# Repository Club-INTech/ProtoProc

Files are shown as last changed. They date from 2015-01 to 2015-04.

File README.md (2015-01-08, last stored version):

# ProtoProc #

## Equipe: ##
- Dédé Belnet
- Martial Costantini
- Pierre-François Gimenez

# Projet: #
Concevoir et construire une console de jeu avec des portes logiques.

## Etapes ##
- concevoir un processeur RISC
- le réaliser électroniquement
- écrire un assembleur
- écrire un compilateur (?)
- écrire un jeu
- intégrer des éléments extérieurs (écran, manette)
- jouer

## Constituant d'un processeur ##
- ALU (unité arithmétique et logique)
- Register file
- Séquenceur
- Horloge
- Contrôleur mémoire
- Contrôleur d'interruption
- MMU

A se répartir.

## Eléments à choisir ##
- Combien de bits? (bits effectivement utilisés + bits de redondance)
- Quels adressages disponibles?
- Jeu d'instruction? (voir plus bas)
- Mode idle?
- Timer? Compteur?

### Proposition ###
- 3 bits (données)
- 8 registres accessibles: ACC1, ACC2, SP (accessible?), flags (zero, sign, carry) (accessible?), index high, index low, E/S 1 (ou seulement entrée), E/S 2 (ou seulement sortie). Registre nul? (utile pour comparaison à zéro et initialisation)
- adressage sur 15 bits immédiats (cf largeur du bus de la mémoire ram de RS)
- adresse sur 15 bits immédiats + 6 bits provenant des deux registres d'index (une adresse du genre 1400 + INDEX)

## Matériel utilisé ##
- transistor
- portes logiques
- décodeur ?
- bascule ?
- (dé)multiplexeur ?
- eeprom ? (mémoire programme et microcode) (utiliser communication parallèle: http://fr.rs-online.com/web/p/memoires-eeprom/0394504/)
- ram ? (mémoire données et mémoire de la carte graphique. Y'a pas de SDRAM traversant chez RS mais y'a du SRAM: http://fr.rs-online.com/web/p/memoires-sram/0538148/)

L'avantage avec un processeur lent, c'est que les temps d'accès mémoire se font en un tic d'horloge...

## Jeu d'instructions ##
Si on veut un jeu rapide, il ne faut pas se contenter de quelques instructions mais ajouter des instructions assez haut niveau.
Il y a deux sortes d'instructions: les câblés (inaltérables) et les micro-codés (programmable).
Les câblés sont plus rapides que les micro-codés, mais consomment beaucoup de portes logiques.

### Instructions câblée monocycle ###
- mov
- Instructions logiques et arithmétiques sur deux registres
- Saut conditionnel (se base sur les flags)
- Saut inconditionnel
- load/store
- nop

### Instructions microcodées à voir selon le jeu. ###
- Pile ? (push, pop, call, ret)
- load/store avec index?
- Echange du contenu de deux registres ?
- Comparaison suivi d'un saut ?
- Instructions sur des booléens ?
- Instructions mémoire-registre ?
- Une instruction de nop'ification qui permettrait de supprimer des branches et de faciliter le travail du pipeline.

Exemple, au lieu de:

```
#!Assembleur

    cmp A, 0
    jz Label1 // (saute si A == 0)
    mov B, 3
    mov A, 6
    jmp Label2
Label1:
    mov B, 9
    mov C, 4
Label2:
```

On aurait:

```
#!Assembleur

    cmp A, 0
    nopz 3 // (si A == 0, ignore les trois prochaines instructions)
    mov B, 3
    mov A, 6
    nop 2  // (ignore les deux prochaines instructions)
    mov B, 9
    mov C, 4
```

On perd du temps (les instructions ignorées durent un cycle chacune) mais cela retire en embranchement. Pour les branchements pour lesquels la nopification est impossible (label en arrière ou trop de code à noper), je rappelle qu'il faut toujours ajouter des nops après le branchement afin de ne pas exécuter les instructions en aval.

```
#!Assembleur

    cmp A, 0
    jz Label1 // saute si A == 0
    nop
    nop
    nop
    (ABWABWA)
Label1:
    (ABWABWABWABWAAAA)
```

## Idées ##
- Un jeu d'instruction dynamique (qui change sans que le processeur ne s'éteigne)
- Il faudrait en plus du processeur et de sa mémoire, une carte son (pour jouer de la musique avec un floppy) et une carte graphique (qui transmet les informations de la mémoire à la matrice de led). Les fréquences de ces trois systèmes ne sont pas forcément les mêmes.
- La carte graphique pourrait gérer une matrice de diode pour les images et des afficheurs 7 segments pour les nombres. Voire utiliser un petit écran LCD.

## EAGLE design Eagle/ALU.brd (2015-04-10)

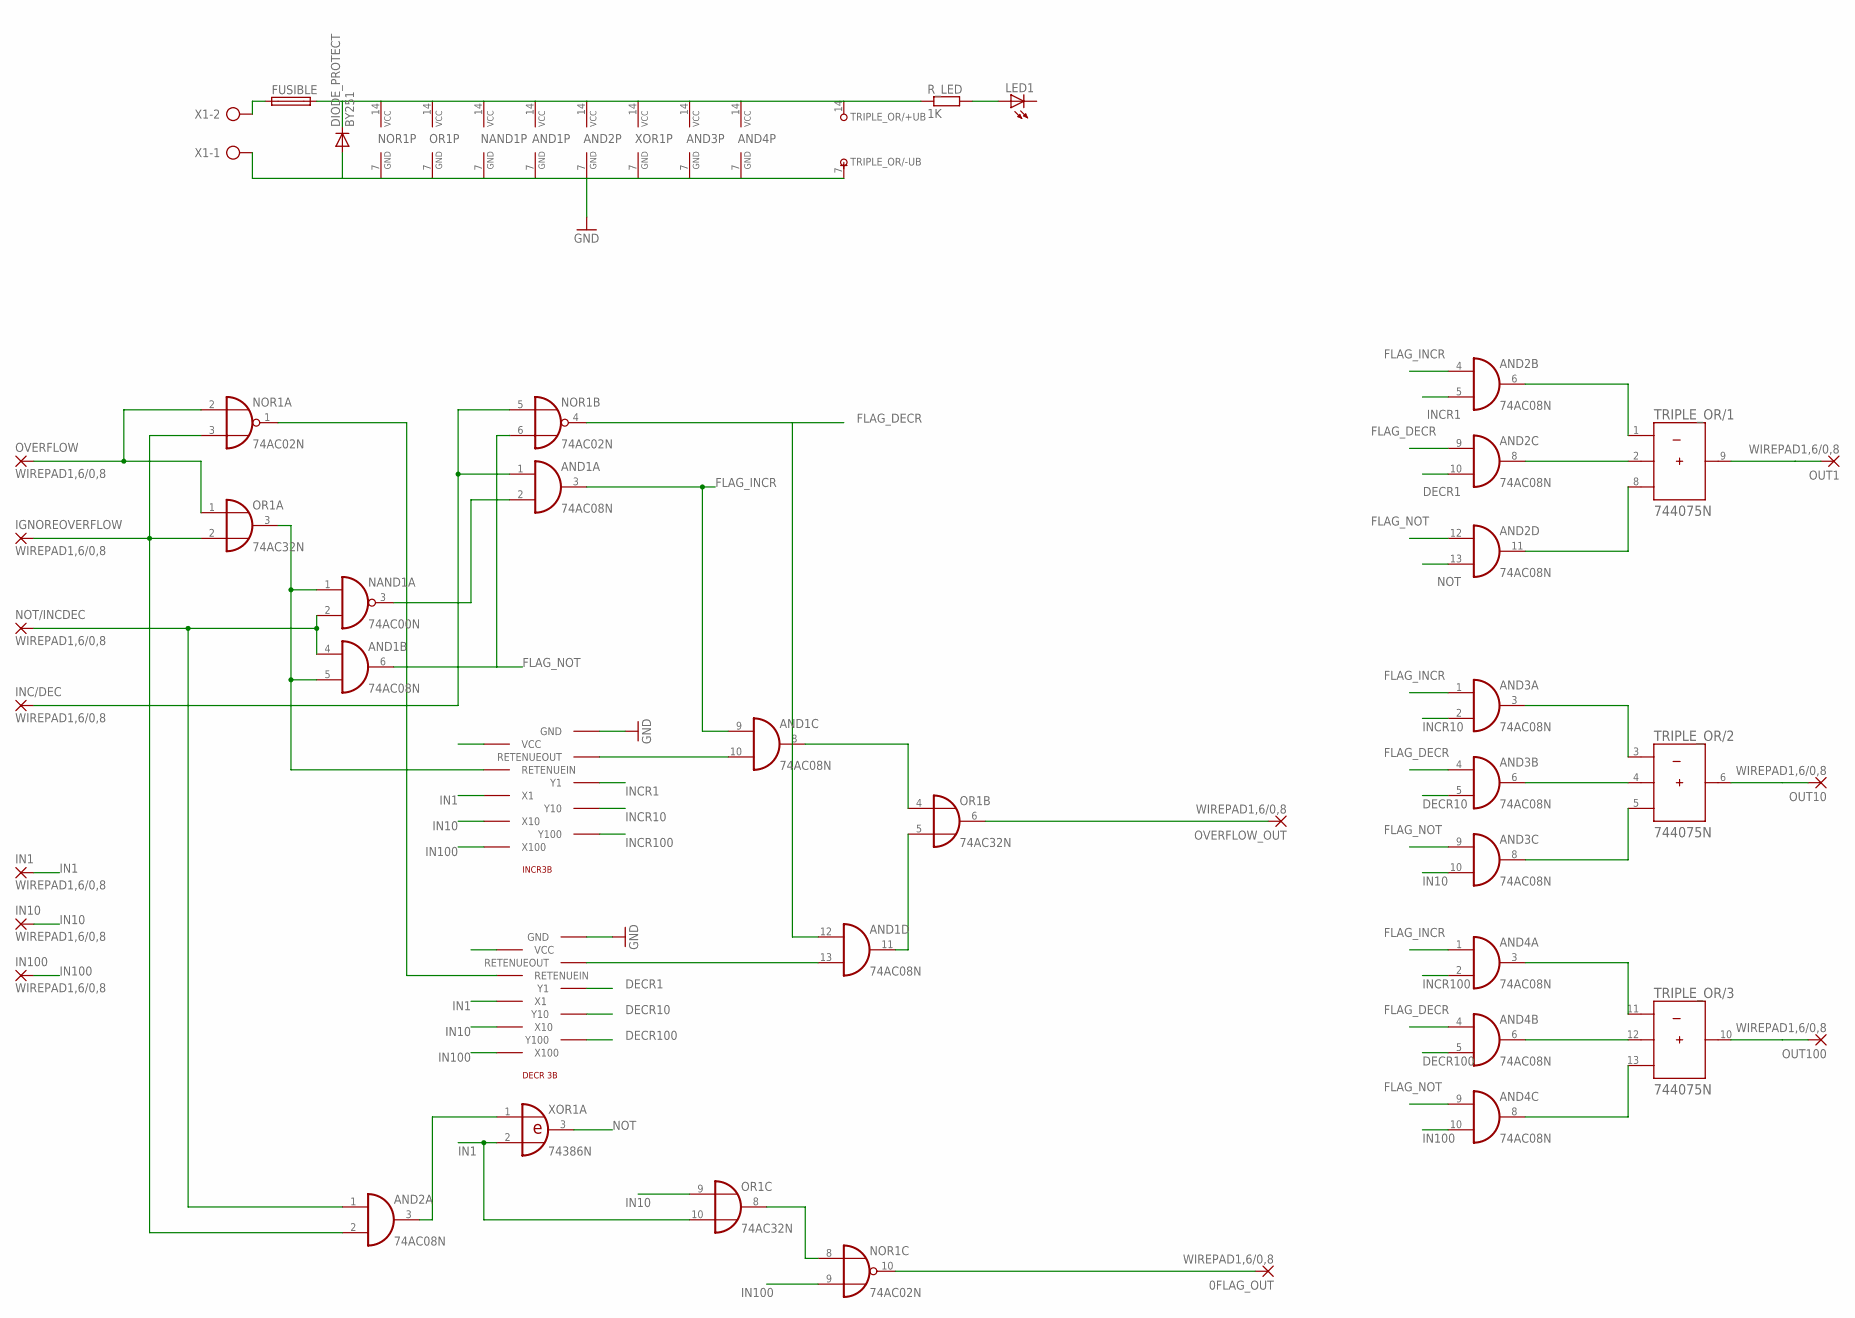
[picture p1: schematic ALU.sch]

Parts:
0FLAG_OUT: WIREPAD1,6/0,8; 1,6/0,8
AND1, AND2, AND3, AND4: 74AC08N; DIL14
DECR3B: DECR3B
DIODE_PROTECT: BY251; DO201-15
FUSIBLE: SH22,5A
IGNOREOVERFLOW: WIREPAD1,6/0,8; 1,6/0,8
IN1, IN10, IN100: WIREPAD1,6/0,8; 1,6/0,8
INC/DEC: WIREPAD1,6/0,8; 1,6/0,8
INCR3B: INCR3B
LED1: LEDSFH482; SFH482
NAND1: 74AC00N; DIL14
NOR1: 74AC02N; DIL14
NOT/INCDEC: WIREPAD1,6/0,8; 1,6/0,8
OR1: 74AC32N; DIL14
OUT1, OUT10, OUT100: WIREPAD1,6/0,8; 1,6/0,8
OVERFLOW: WIREPAD1,6/0,8; 1,6/0,8
OVERFLOW_OUT: WIREPAD1,6/0,8; 1,6/0,8
R_LED: 1K; 0207/10
TRIPLE_OR: 744075N; DIL14
X1: AK300/2
XOR1: 74386N; DIL14

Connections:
0FLAG_OUT: 0FLAG_OUT.1, NOR1.10 (O)
DECR1: AND2.10 (I1), DECR3B.Y1
DECR10: AND3.5 (I1), DECR3B.Y10
DECR100: AND4.5 (I1), DECR3B.Y100
FLAG_DECR: AND1.12 (I0), AND2.9 (I0), AND3.4 (I0), AND4.4 (I0), NOR1.4 (O)
FLAG_INCR: AND1.3 (O), AND1.9 (I0), AND2.4 (I0), AND3.1 (I0), AND4.1 (I0)
FLAG_NOT: AND1.6 (O), AND2.12 (I0), AND3.9 (I0), AND4.9 (I0), NOR1.6 (I1)
GND: AND1.7 (GND), AND2.7 (GND), AND3.7 (GND), AND4.7 (GND), DECR3B.GND, DIODE_PROTECT.A, INCR3B.GND, NAND1.7 (GND), NOR1.7 (GND), OR1.7 (GND), TRIPLE_OR.7 (-UB), X1.1, XOR1.7 (GND)
IN1: DECR3B.X1, IN1.1, INCR3B.X1, OR1.10 (I1), XOR1.2 (I1)
IN10: AND3.10 (I1), DECR3B.X10, IN10.1, INCR3B.X10, OR1.9 (I0)
IN100: AND4.10 (I1), DECR3B.X100, IN100.1, INCR3B.X100, NOR1.9 (I1)
INCR1: AND2.5 (I1), INCR3B.Y1
INCR10: AND3.2 (I1), INCR3B.Y10
INCR100: AND4.2 (I1), INCR3B.Y100
unnamed: NOR1.2 (I0), OR1.1 (I0), OVERFLOW.1
unnamed: AND2.6 (O), TRIPLE_OR.1 (A)
unnamed: AND1.2 (I1), NAND1.3 (O)
unnamed: AND1.1 (I0), INC/DEC.1, NOR1.5 (I0)
unnamed: AND1.4 (I0), AND2.1 (I0), NAND1.2 (I1), NOT/INCDEC.1
unnamed: AND1.5 (I1), INCR3B.RETENUEIN, NAND1.1 (I0), OR1.3 (O)
unnamed: AND2.8 (O), TRIPLE_OR.2 (B)
unnamed: DECR3B.RETENUEIN, NOR1.1 (O)
unnamed: AND1.8 (O), OR1.4 (I0)
unnamed: AND1.13 (I1), DECR3B.RETENUEOUT
unnamed: AND1.10 (I1), INCR3B.RETENUEOUT
unnamed: AND1.11 (O), OR1.5 (I1)
unnamed: OR1.6 (O), OVERFLOW_OUT.1
unnamed: AND2.2 (I1), IGNOREOVERFLOW.1, NOR1.3 (I1), OR1.2 (I1)
unnamed: AND2.3 (O), XOR1.1 (I0)
unnamed: NOR1.8 (I0), OR1.8 (O)
unnamed: AND2.11 (O), TRIPLE_OR.8 (C)
unnamed: FUSIBLE.1, X1.2
unnamed: LED1.A, R_LED.2
unnamed: AND3.3 (O), TRIPLE_OR.3 (A)
unnamed: AND3.6 (O), TRIPLE_OR.4 (B)
unnamed: AND3.8 (O), TRIPLE_OR.5 (C)
unnamed: AND4.3 (O), TRIPLE_OR.11 (A)
unnamed: AND4.6 (O), TRIPLE_OR.12 (B)
unnamed: AND4.8 (O), TRIPLE_OR.13 (C)
NOT: AND2.13 (I1), XOR1.3 (O)
OUT1: OUT1.1, TRIPLE_OR.9 (Y)
OUT10: OUT10.1, TRIPLE_OR.6 (Y)
OUT100: OUT100.1, TRIPLE_OR.10 (Y)
VCC: AND1.14 (VCC), AND2.14 (VCC), AND3.14 (VCC), AND4.14 (VCC), DECR3B.VCC, DIODE_PROTECT.C, FUSIBLE.2, INCR3B.VCC, NAND1.14 (VCC), NOR1.14 (VCC), OR1.14 (VCC), R_LED.1, TRIPLE_OR.14 (+UB), XOR1.14 (VCC)

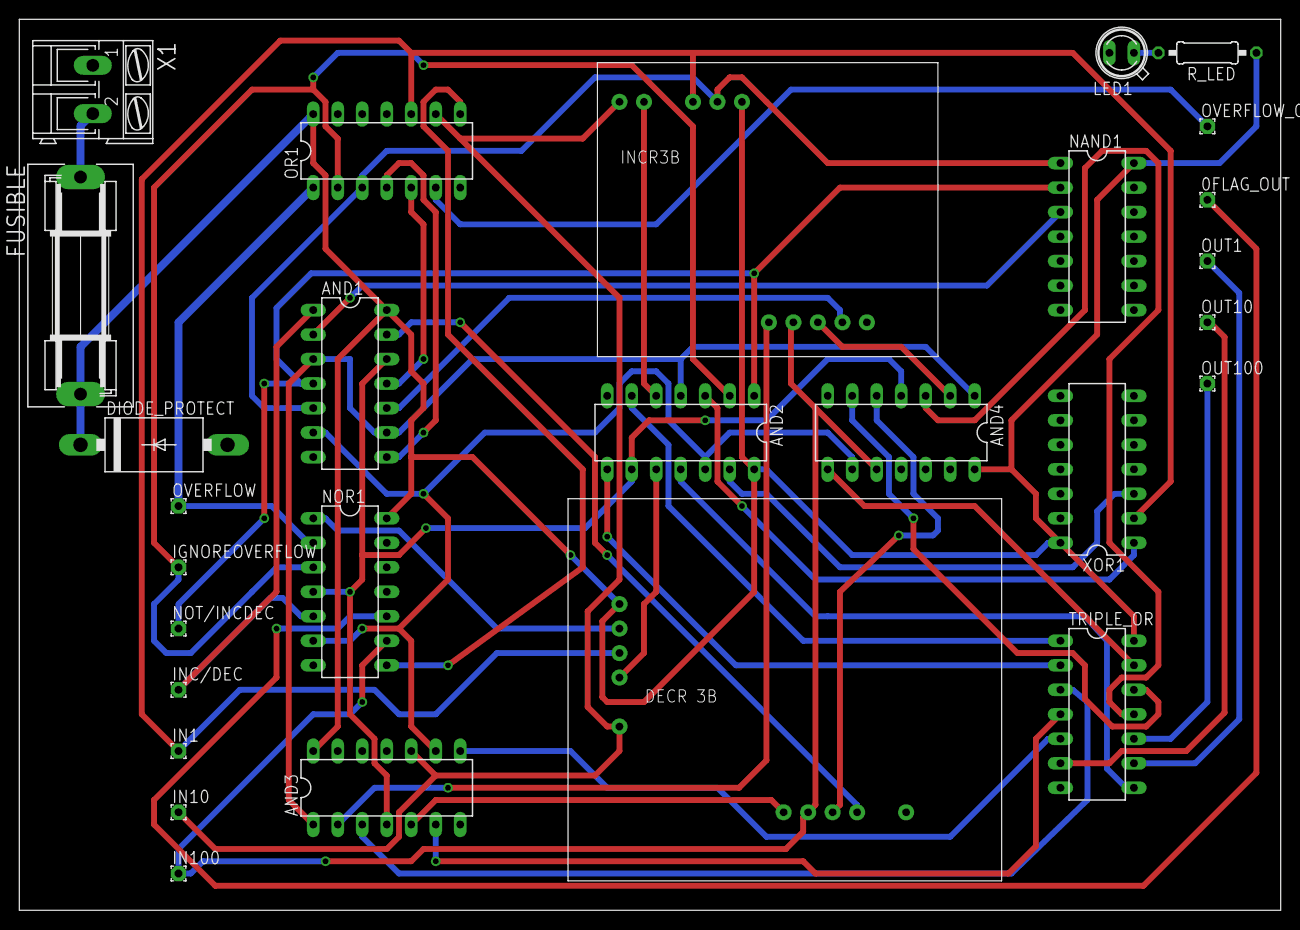
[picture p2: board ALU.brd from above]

Board: 2 copper layers, 130.8 x 92.4 mm, 28 parts (0 on the bottom side), 44 nets.

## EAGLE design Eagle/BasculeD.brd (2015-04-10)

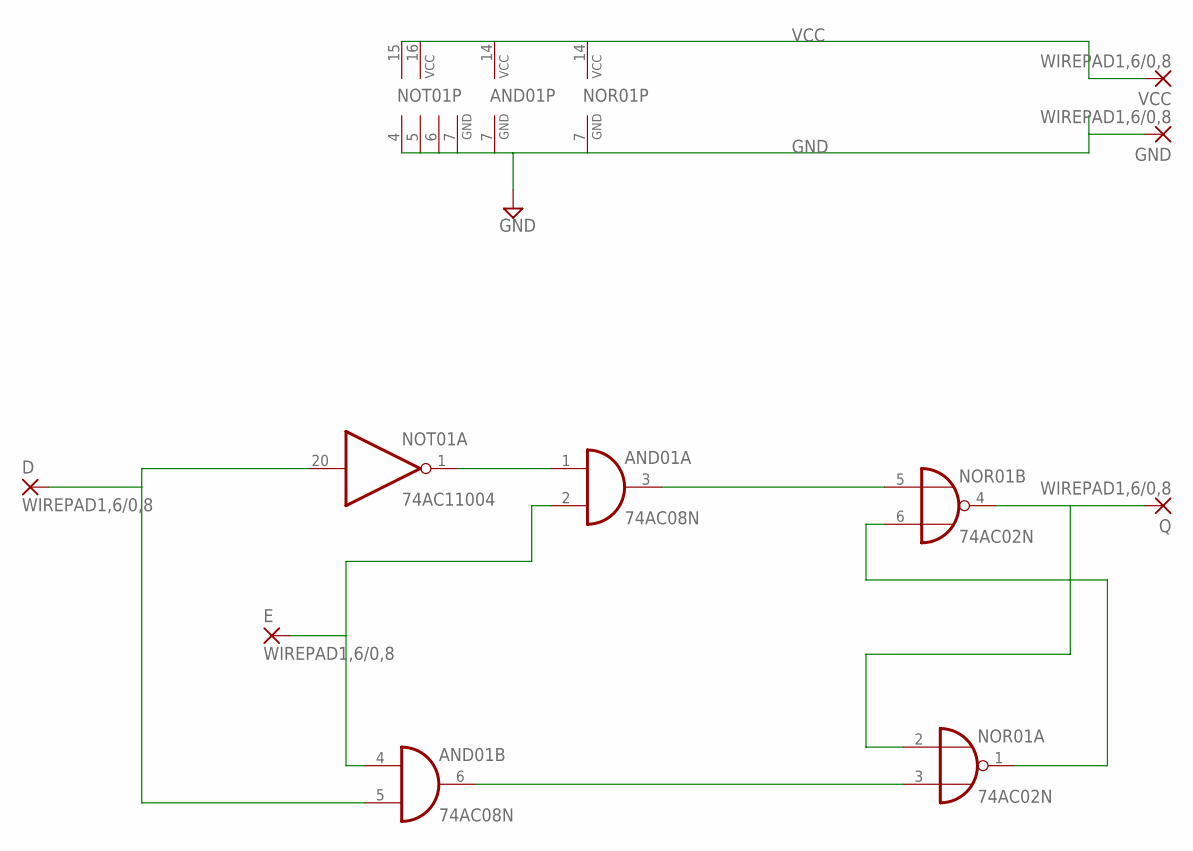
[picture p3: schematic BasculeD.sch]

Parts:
AND01: 74AC08N; DIL14
D: WIREPAD1,6/0,8; 1,6/0,8
E: WIREPAD1,6/0,8; 1,6/0,8
GND: WIREPAD1,6/0,8; 1,6/0,8
NOR01: 74AC02N; DIL14
NOT01: 74AC11004; DIL20
Q: WIREPAD1,6/0,8; 1,6/0,8
VCC: WIREPAD1,6/0,8; 1,6/0,8

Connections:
GND: AND01.7 (GND), GND.1, NOR01.7 (GND), NOT01.4 (GND), NOT01.5 (GND), NOT01.6 (GND), NOT01.7 (GND)
unnamed: AND01.1 (I0), NOT01.1 (O)
unnamed: AND01.3 (O), NOR01.5 (I0)
unnamed: NOR01.1 (O), NOR01.6 (I1)
unnamed: AND01.6 (O), NOR01.3 (I1)
unnamed: AND01.2 (I1), AND01.4 (I0), E.1
unnamed: AND01.5 (I1), D.1, NOT01.20 (I)
NOR01: NOR01.2 (I0), NOR01.4 (O), Q.1
VCC: AND01.14 (VCC), NOR01.14 (VCC), NOT01.15 (VCC), NOT01.16 (VCC), VCC.1

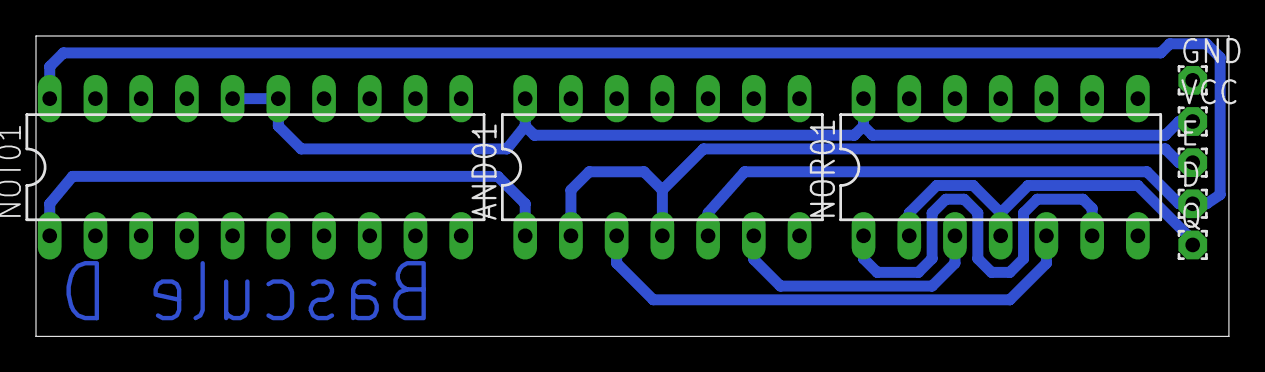
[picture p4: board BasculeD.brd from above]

Board: 2 copper layers, 66.3 x 16.7 mm, 8 parts (0 on the bottom side), 9 nets.

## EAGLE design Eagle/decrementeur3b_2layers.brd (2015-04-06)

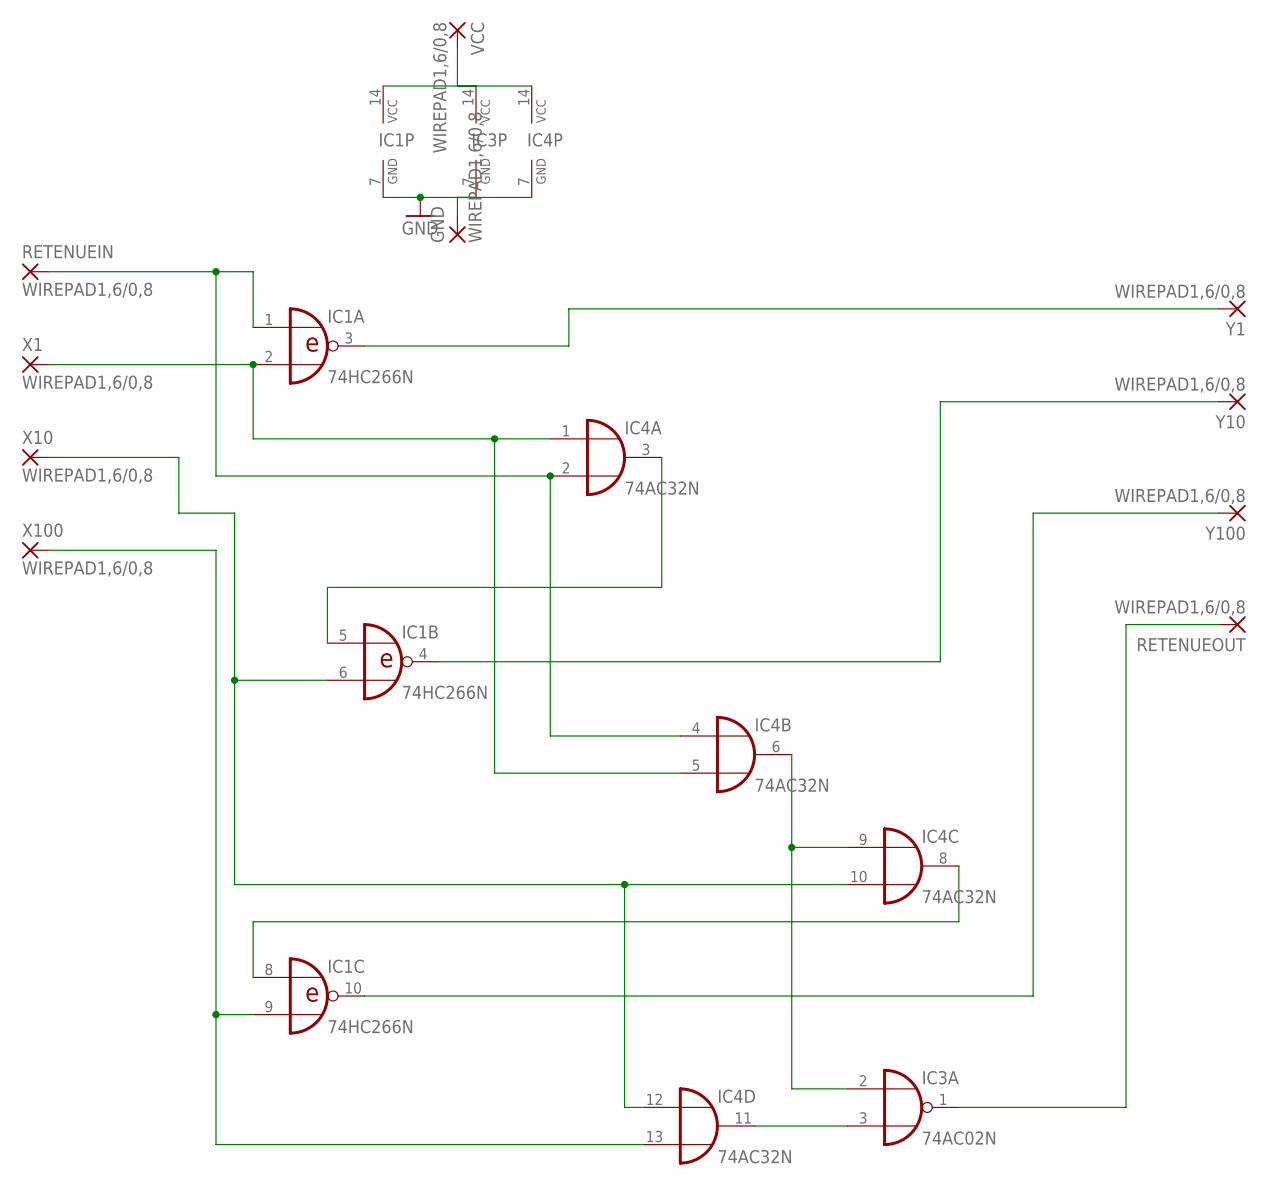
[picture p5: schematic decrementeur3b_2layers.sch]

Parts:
GND: WIREPAD1,6/0,8; 1,6/0,8
IC1: 74HC266N; DIL14
IC3: 74AC02N; DIL14
IC4: 74AC32N; DIL14
RETENUEIN: WIREPAD1,6/0,8; 1,6/0,8
RETENUEOUT: WIREPAD1,6/0,8; 1,6/0,8
VCC: WIREPAD1,6/0,8; 1,6/0,8
X1, X10, X100: WIREPAD1,6/0,8; 1,6/0,8
Y1, Y10, Y100: WIREPAD1,6/0,8; 1,6/0,8

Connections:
GND: GND.1, IC1.7 (GND), IC3.7 (GND), IC4.7 (GND)
unnamed: IC1.2 (I1), IC4.1 (I0), IC4.5 (I1), X1.1
unnamed: IC1.1 (I0), IC4.2 (I1), IC4.4 (I0), RETENUEIN.1
unnamed: IC1.3 (O), Y1.1
unnamed: IC3.2 (I0), IC4.6 (O), IC4.9 (I0)
unnamed: IC1.8 (I0), IC4.8 (O)
unnamed: IC1.9 (I1), IC4.13 (I1), X100.1
unnamed: IC1.6 (I1), IC4.10 (I1), IC4.12 (I0), X10.1
unnamed: IC1.10 (O), Y100.1
unnamed: IC1.4 (O), Y10.1
unnamed: IC3.3 (I1), IC4.11 (O)
unnamed: IC3.1 (O), RETENUEOUT.1
VCC: IC1.14 (VCC), IC3.14 (VCC), IC4.14 (VCC), VCC.1

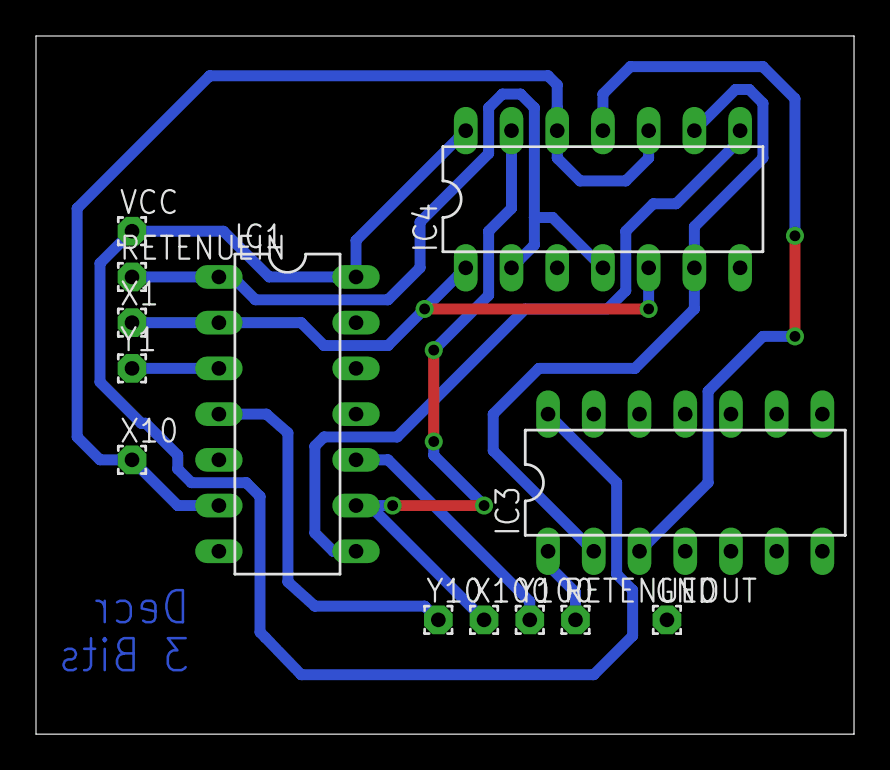
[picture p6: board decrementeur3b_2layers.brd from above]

Board: 2 copper layers, 45.4 x 38.8 mm, 13 parts (0 on the bottom side), 13 nets.

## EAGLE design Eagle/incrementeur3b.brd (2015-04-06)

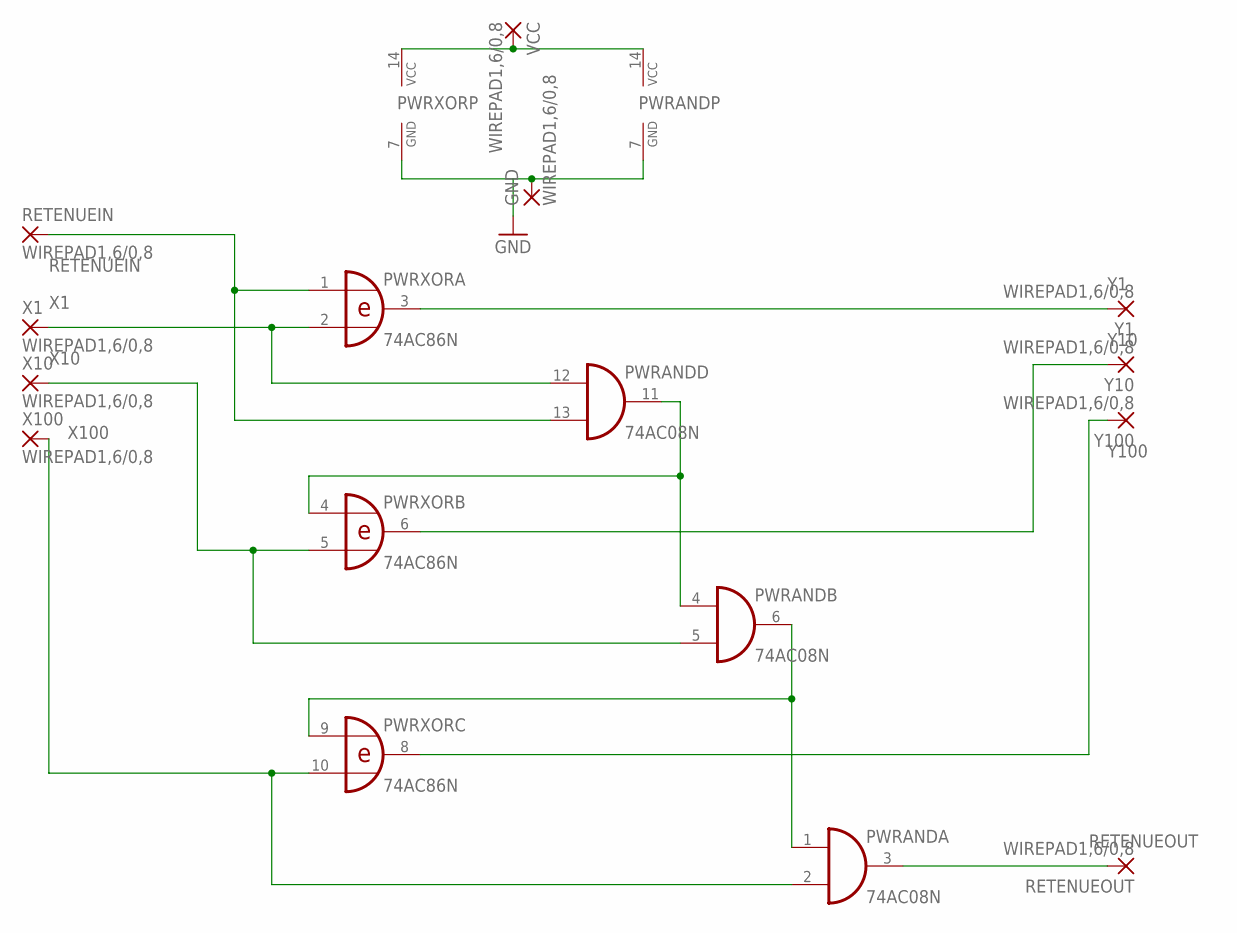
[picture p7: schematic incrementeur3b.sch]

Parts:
GND: WIREPAD1,6/0,8; 1,6/0,8
PWRAND: 74AC08N; DIL14
PWRXOR: 74AC86N; DIL14
RETENUEIN: WIREPAD1,6/0,8; 1,6/0,8
RETENUEOUT: WIREPAD1,6/0,8; 1,6/0,8
VCC: WIREPAD1,6/0,8; 1,6/0,8
X1, X10, X100: WIREPAD1,6/0,8; 1,6/0,8
Y1, Y10, Y100: WIREPAD1,6/0,8; 1,6/0,8

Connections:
GND: GND.1, PWRAND.7 (GND), PWRXOR.7 (GND)
unnamed: PWRAND.14 (VCC), PWRXOR.14 (VCC), VCC.1
unnamed: PWRAND.4 (I0), PWRAND.11 (O), PWRXOR.4 (I0)
unnamed: PWRAND.1 (I0), PWRAND.6 (O), PWRXOR.9 (I0)
RETENUEIN: PWRAND.13 (I1), PWRXOR.1 (I0), RETENUEIN.1
RETENUEOUT: PWRAND.3 (O), RETENUEOUT.1
X1: PWRAND.12 (I0), PWRXOR.2 (I1), X1.1
X10: PWRAND.5 (I1), PWRXOR.5 (I1), X10.1
X100: PWRAND.2 (I1), PWRXOR.10 (I1), X100.1
Y1: PWRXOR.3 (O), Y1.1
Y10: PWRXOR.6 (O), Y10.1
Y100: PWRXOR.8 (O), Y100.1

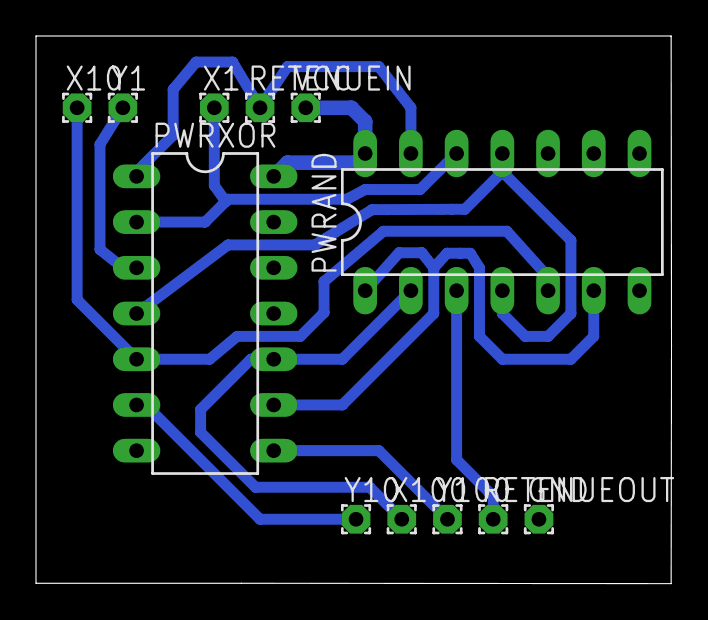
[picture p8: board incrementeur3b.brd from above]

Board: 2 copper layers, 35.3 x 30.4 mm, 12 parts (0 on the bottom side), 12 nets.

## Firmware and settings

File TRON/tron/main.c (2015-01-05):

#include <stdio.h>
#include <stdlib.h>
#include <time.h>

#define HAUTEUR 10
#define LARGEUR 10
#define LONGUEUR 5

#define NB_JOUEURS 2

#define TRUE 1
#define FALSE 0

#define HAUT 0
#define DROITE 1
#define BAS 2
#define GAUCHE 3

void affiche();
void init();

unsigned char table[LARGEUR][HAUTEUR]; // nb de joueur, 0 si rien, 255 si bloc
unsigned char joueurs[NB_JOUEURS][LONGUEUR][2];
unsigned char indice[NB_JOUEURS] = {0, 0};
unsigned char direction[NB_JOUEURS] = {HAUT, HAUT};
unsigned char ok = FALSE;
char dir_x[5] = {0, 1, 0, -1, 0};

char i, j;
char in;

int main()
{
    init();

    while(1)
    {
        for(i = 0; i < NB_JOUEURS; i++)
        {

mov reg0, NB_JOUEURS
boucleJeu:
dec reg0

            affiche();
            scanf("%d", &in);

            if(in == 8)
                direction[i] = HAUT;
            else if(in == 4)
                direction[i] = GAUCHE;
            else if(in == 6)
                direction[i] = DROITE;
            else if(in == 2)
                direction[i] = BAS;

// on n'aura qu'à lire les registres qui contiennent les valeurs. On fera en sorte qu'électriquement, le registre conserve la dernière valeur non nulle

            int old_x = joueurs[i][indice[i]][0];
            int old_y = joueurs[i][indice[i]][1];

mov index0, 0
mov index1, reg0
mov index2, 0
mov index3, 4
movd reg2:reg1, [index] // reg3:reg2 contient indice[i]
// index0 vaut 0
mov index1, reg1
mov index2, reg2
mov index3, reg0
movd reg7:reg6:reg5:reg4:reg3, [index] // ils contiennent les anciennes valeurs de X et Y
            ok |= ((indice[i]+1) == LONGUEUR);

            indice[i]++;
            indice[i] %= LONGUEUR;

inc reg1
cinc reg2 // incrémentation de indice[i]
// le modulo est automatique

mov index0, 0
mov index1, reg0
mov index2, 0
mov index3, 4
movd [index], reg2:reg1 // on enregistre la nouvelle valeur

jnz reg3, pasNouveauOk
jnz reg2, pasNouveauOk
mov reg8, 0 // nul: ok est vrai
// (ne pas oublier d'initialiser reg10 à une valeur non nulle)

pasNouveauOk:
jnz reg8, pasOk

            if(ok)
                table[joueurs[i][indice[i]][0]][joueurs[i][indice[i]][1]] = 0;

mov index0, 0
mov index1, reg2
mov index2, reg3
mov index3, reg0
movd index, [index] // on récupère l'abscisse à cet indice
movg [index], 0 // et on y met 0

pasOk: // on a fini la condition

            joueurs[i][indice[i]][0] = (old_x+dir_x[direction[i]]+LARGEUR)%LARGEUR;
            joueurs[i][indice[i]][1] = (old_y+dir_x[direction[i]+1]+HAUTEUR)%HAUTEUR;

mov reg1, INJ1 // input joueur 1
jnz reg1, pas0

//00 : HAUT
inc reg3
cinc reg4
cxor reg5
jmp finCondition

pas0:
dec reg1
jnz reg1, pas1
//01 : BAS
dec reg3
cdec reg4
cxor reg5, 1
jmp finCondition

pas1:
dec reg1
jnz reg1, pas2
//10 : GAUCHE
dec reg5
cdec reg6
cdec reg7
dec reg5
cdec reg6
cdec reg7
jmp finCondition

pas2:
// du coup, c'est forcément 3
//11 : DROITE
inc reg5
cinc reg6
cinc reg7
inc reg5
cinc reg6
cinc reg7

finCondition:

mov index0, 0
mov index1, reg2
mov index2, reg3
mov index3, reg0

movd [index], reg7:reg6:reg5:reg4:reg3

            if(table[joueurs[i][indice[i]][0]][joueurs[i][indice[i]][1]] != 0)
            {
                printf("Joueur %d a perdu!", i+1);
                return EXIT_SUCCESS;
            }

mov index0, reg3
mov index1, reg4
mov index2, reg5
mov index3, reg6
mov index4, reg7

movg reg1, [index]
jnz finJeu

            table[joueurs[i][indice[i]][0]][joueurs[i][indice[i]][1]] = i+1;

mov reg2, reg0
inc reg2
movg [index], reg2

        }
jnz reg0, boucleInitJoueurs
mov reg0, NB_JOUEURS
jmp boucleInitJoueurs
    }

    return 0;
}

finJeu: 
TODO...

void affiche()
{
    char i, j;
    for(j = 0; j < HAUTEUR; j++)
    {
        printf("\n");
        for(i = 0; i < LARGEUR; i++)
        {
            if(table[i][HAUTEUR-j-1] == 0)
                printf(".");
            else if(table[i][HAUTEUR-j-1] >= 1 && table[i][HAUTEUR-j-1] < 255)
                printf("%c",'A'+table[i][HAUTEUR-j-1]-1);
            else if(table[i][HAUTEUR-j-1] == 255)
                printf("X");
        }
    }
    printf("\n");

}

void init()
{

mov reg8, 1
    // initialisation de la table (sans obstacles ici)
    for(i = 0; i < LARGEUR; i++)
        for(j = 0; j < HAUTEUR; j++)
            table[i][j] = 0;

mov index, 0 ;taille tableau = indice max + 1 = overflow, on retombe à 0
boucleInitTable:
dec index
movg [index], 0
cmp index
jnz boucleInitTable

    srand(time(NULL));

    for(i = 0; i < 10; i++)
        table[rand()%LARGEUR][rand()%HAUTEUR] = 255;

mov reg0, 10 // valeur à ajuster...
mov reg1, MUR
boucleInitTableRandom:
rnd index0
rnd index1
rnd index2
rnd index3
rnd index4
movg [index], reg1
dec reg0
cmp reg0
jnz boucleInitTableRandom


    for(i = 0; i < NB_JOUEURS; i++)
    {
mov reg0, NB_JOUEURS
boucleInitJoueurs:
dec reg0

        do {
            // init des positions des joueurs
            joueurs[i][0][0] = rand()%LARGEUR;
            joueurs[i][0][1] = rand()%HAUTEUR;
        } while(table[joueurs[i][0][0]][joueurs[i][0][1]] != 0);
        table[joueurs[i][0][0]][joueurs[i][0][1]] = i+1; // on note l'obstacle

boucleInitPositionJoueur:
rnd index0
rnd index1
rnd index2
rnd index3
rnd index4
movg reg1, [index]
cmp reg1
jnz boucleInitPositionJoueur
movg [index], reg0 // reg0 contient le numéro du joueur
mov reg1, index0
mov reg2, index1
mov reg3, index2
mov reg4, index3
mov reg5, index4



        for(j = 1; j < LONGUEUR; j++)
        {
            joueurs[i][j][0] = joueurs[i][0][0];
            joueurs[i][j][1] = joueurs[i][0][1];
        }

mov index0, 0 // pour l'abscisse
mov index1, 0
mov index2, 0 // dernier élément de la queue + 1
mov index3, reg0 // numéro du joueur
boucleInitQueue:
dec index1
cdec index2
movd [index], reg5:reg4:reg3:reg2:reg1
jnz index1, boucleInitQueue
jnz index2, boucleInitQueue

jnz reg0, boucleInitJoueurs

    }

}

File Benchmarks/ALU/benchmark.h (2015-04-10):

/** \file benchmark.h
 *  \author Dede
 *  \brief l'include correspondant au vrai code
 * 
 */

#ifndef benchmark_h
#define benchmark_h

#include <stdint.h>
#include <avr/io.h>
#include <util/delay.h>
#include <string.h>
#include <libintech/uart.hpp>
#include <libintech/gpio.hpp>
#include <libintech/singleton.hpp>

#define INPUT_SIZE 7
#define OUTPUT_SIZE 5
#define POSSIBLE_INPUTS 128
#define PROCESSOR_DELAY 10000	//le d�lai entre deux utilisations de l'ALU, en microsecondes

#define overflow input[0]
#define ign_overflow input[1]
#define NOT input[2]
#define INC input[3]
#define i001 input[4]
#define i010 input[5]
#define i100 input[6]

#define overflow_out output[0]
#define zero_out output[1]
#define o001 output[2]
#define o010 output[3]
#define o100 output[4]

#define AND(X,Y) ((X && Y) ? 1 : 0)
#define OR(X,Y) ((X || Y) ? 1 : 0)
#define NAND(X,Y) (AND(X,Y)? 0 : 1)
#define NOR(X,Y) (OR(X,Y)? 0 : 1)
#define XOR(X,Y) (X != Y)
#define NO(X) (X ? 0 : 1)
#define 3-OR(X,Y,Z) (OR(X,OR(Y,Z)))

class Benchmark : public Singleton<Benchmark>{
// Par défaut les attributs sont publics dans une struct


private:
	
    typedef uart0 serial_t_;
    uint8_t input[INPUT_SIZE];
    uint8_t output[OUTPUT_SIZE];
    uint8_t actual_output[OUTPUT_SIZE]; 
    uint8_t incr[3];
    uint8_t decr[3];
    uint8_t retenue_in_incr;
    uint8_t retenue_in_decr;
    uint8_t retenue_out_incr;
    uint8_t retenue_out_decr;
    uint8_t flag_incr;
    uint8_t flag_decr;
    uint8_t flag_not;
    uint8_t onot;
    
    void alu_test();
    void alu_logic();
    void incr_logic();
    void decr_logic();
    void alu_once(const unsigned int number);
    void fill_input(const unsigned int number);
    void apply_input();
    void read_output();
    void compare_outputs();
    const char* get_input();
    const char* get_output();
    const char* get_actual_output();
    unsigned int twopow(unsigned int pow);
    unsigned int string_to_uint(const char* buffer);
    
public:
    
    Benchmark();
    
    //gestion des mesures courantes
 
    void communiquer_pc();

};

#endif

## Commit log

2014-06-21 Circuits écrits avec logisim
2014-11-24 Tron en assembleur (en cours)
2015-01-05 Code assembleur écrit
2015-01-09 Optimisation de l'alu
2015-03-08 Debug des problèmes de nommage
2015-03-08 Doc, suppression de vieux trucs
2015-03-09 Debut de l'IDE pour le dev du code de tron. La coloration syntaxique marche pour les mnémoniques et les chiffres
2015-03-09 IDE terminé! coloration syntaxique complete, et numerotation de lignes. Plus qu'a faire le code d'assemblage et la machine virtuelle xD
2015-03-18 Les .sch et .brd de l'ALU, plus quelques modifs de la partie logique
    [ALU.brd, ALU.sch, ALUprudente.sch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]
2015-03-18 Retrait de toutes les versions inutiles des .sch et des .brd
2015-04-07 Code de benchmarks pour l'ALU
    [ALU.brd, ALU.sch]
2015-04-07 Le code pour les benchmarks de l'ALU sur Arduino 328p. Non testé
2015-04-08 Modification de la forme de la monoinstruction
2015-04-09 board Bascule D
    [BasculeD.brd, BasculeD.sch]
2015-04-10 finalisation du routage bascule D
    [BasculeD.brd]
